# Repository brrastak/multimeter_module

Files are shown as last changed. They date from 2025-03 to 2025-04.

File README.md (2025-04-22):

# Module for Fluke 87V Multimeter

## Description

This module connects to the "COM" and "mA" inputs of the Fluke 87V multimeter. It allows you to:

- Disconnect the power source from the tested circuit.
- Short the multimeter's internal current shunt.
- Protect the multimeter using an external fuse.

Partially parametrized via spreadsheet in FreeCAD project.

## Printing

The enclosure was 3D printed using 0.2 mm layer height PETG filament.  
Threading for an M3 screw should be cut manually after printing.

## Images

### Photos

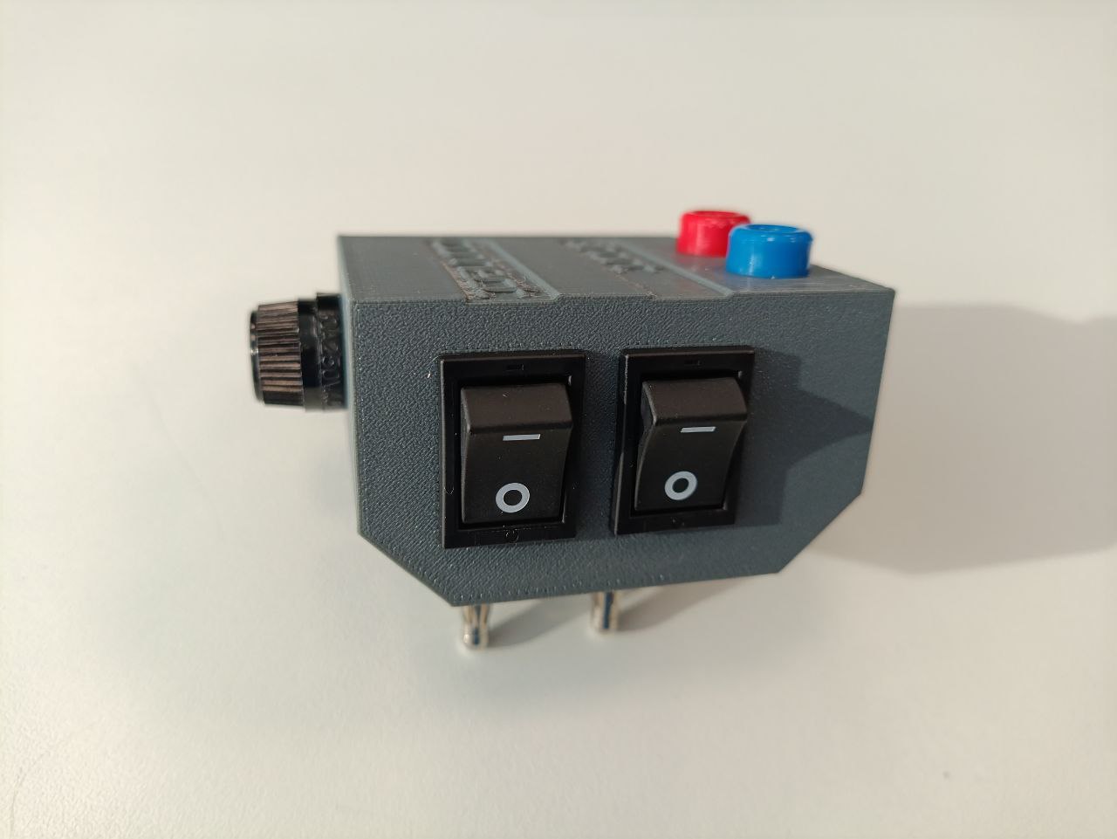
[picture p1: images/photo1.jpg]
Module

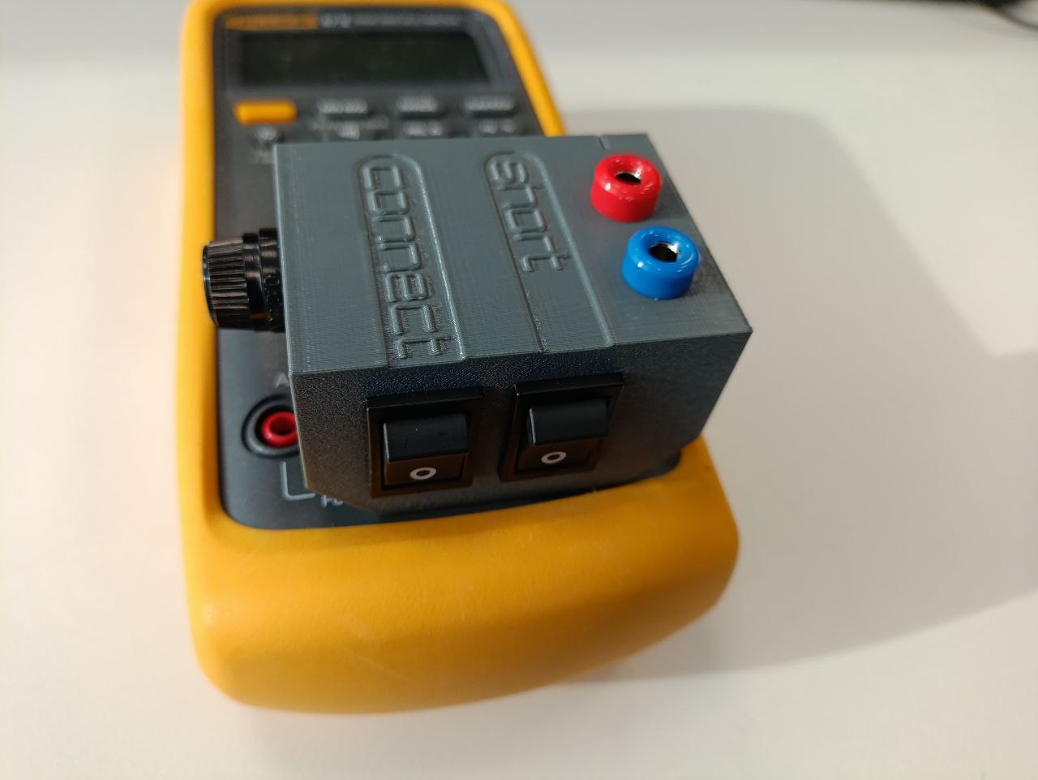
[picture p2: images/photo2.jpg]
Module + multimeter


### Drawings

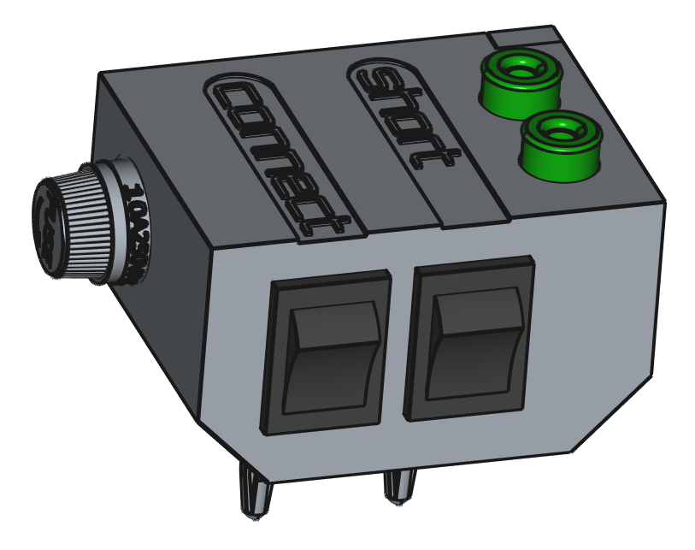
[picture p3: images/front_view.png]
Front view

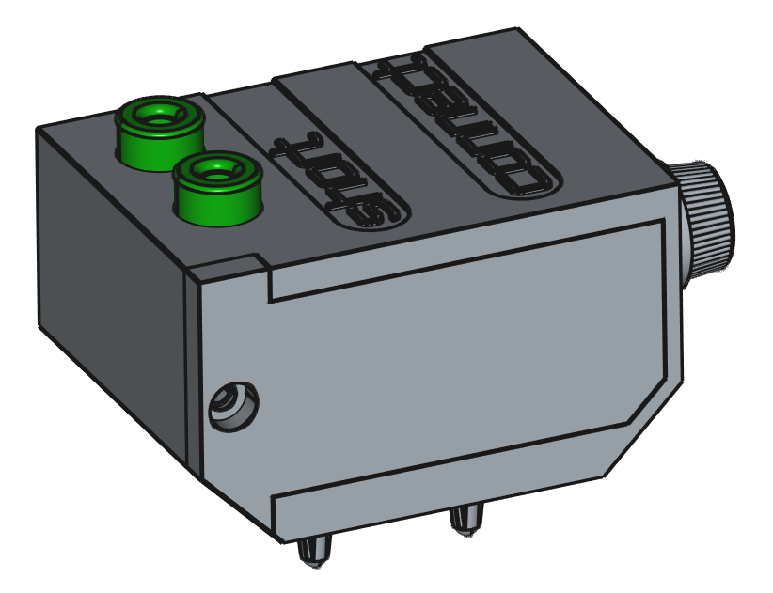
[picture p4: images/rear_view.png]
Rear view

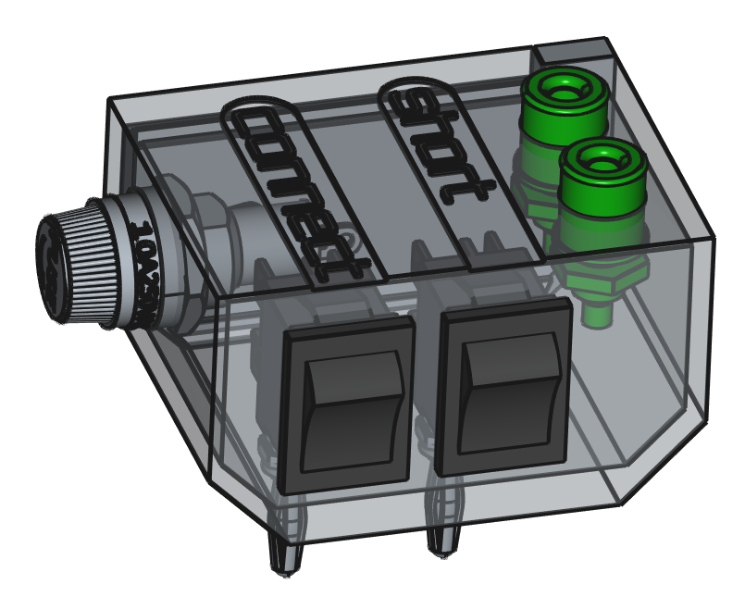
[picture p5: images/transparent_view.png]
Transparent view


### Schematic

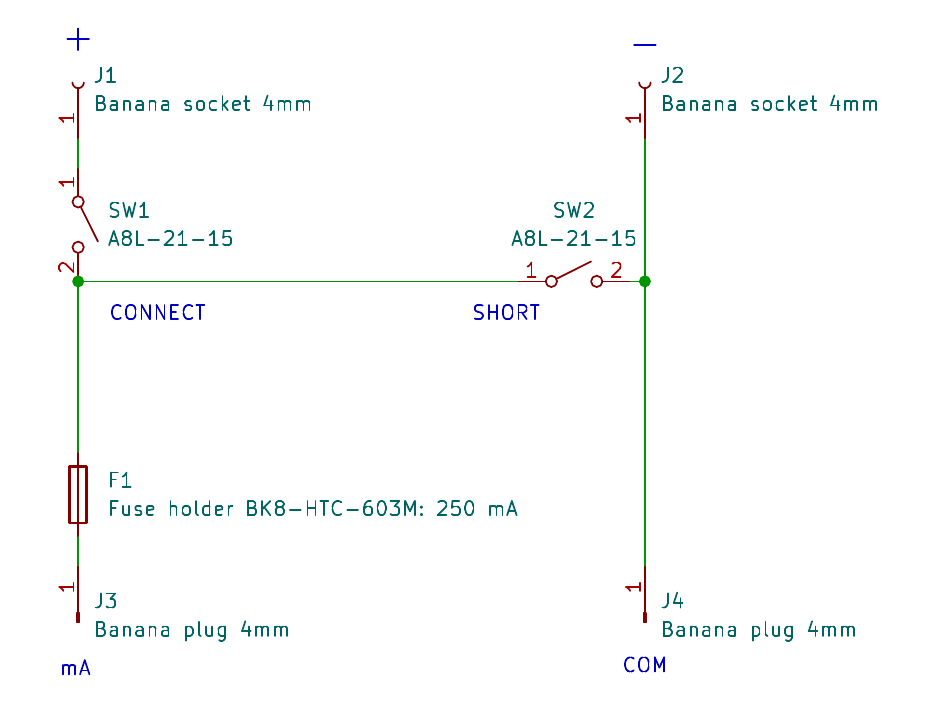
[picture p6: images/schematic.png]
Schematic


### Wiring

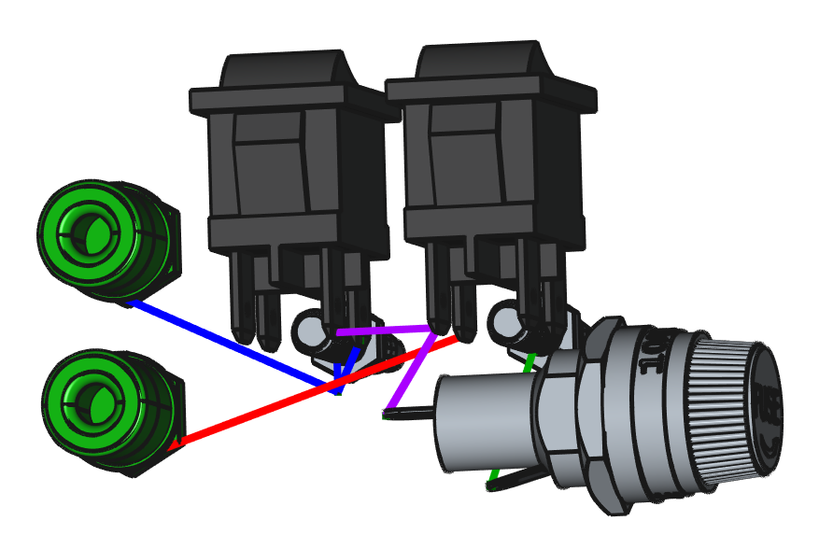
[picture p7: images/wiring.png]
Wiring


## Bill of Materials (BOM)

| Designator  | Description | Value | Qty | Farnell Code  | Note |
|---|---|---|-----|---|---|
| F1 | Fuse holder | BK8-HTC-603M  | 1 | 3769131 | |
| | Fast fuse | 250 mA | 1 | 3515934 | |
| J1, J2 | Banana socket 4mm/M6  | | 2 | 1698955 | |
| | Solder washer M6 | | 2 | 2832547 | |
| | Star lock washer M6 | | 2 | | |
| J3, J4 | Banana plug 4mm | FK 1210 NI | 2 | 3224621 | |
| | Solder washer M4 | | 2 | 2832545 | |
| | Nylon lock nut M4 | | 2 | | |
| SW1, SW2 | DPST switch | A8L-21-15 | 2 | 2213918 | SPST won't fit mechanically |
| | Blade connector 4.8 | | 4 | | |

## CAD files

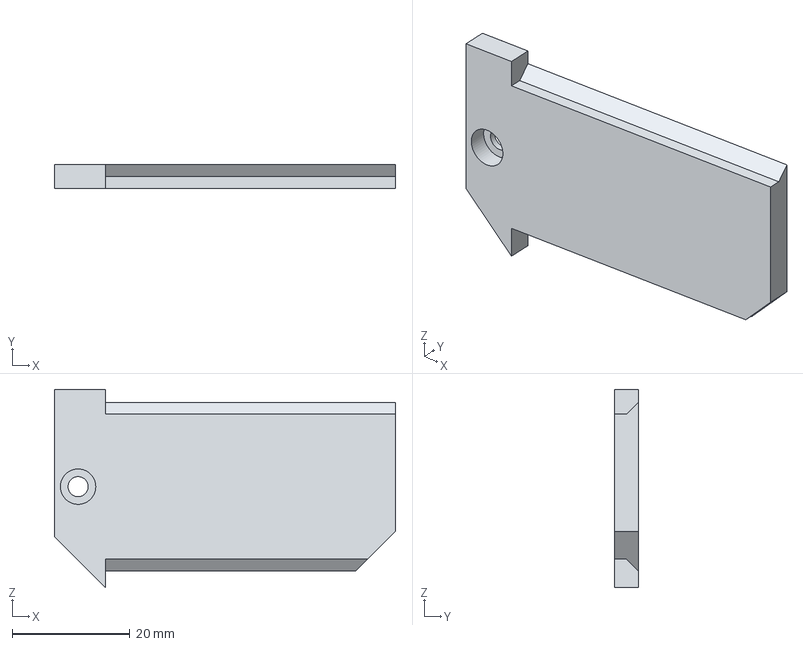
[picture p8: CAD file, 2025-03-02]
3D/lid.step
57.8 x 4.00 x 33.6 mm

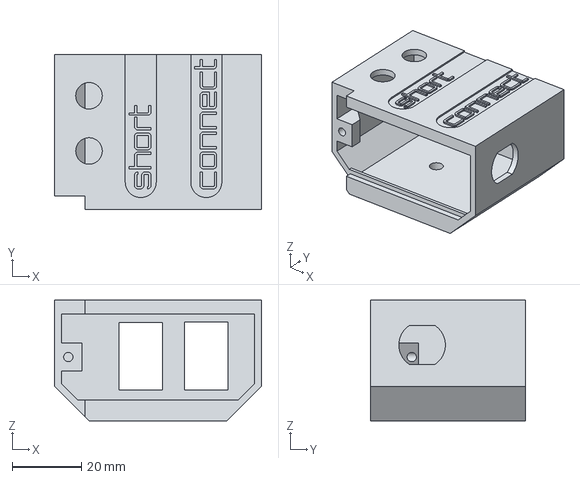
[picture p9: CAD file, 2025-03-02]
3D/box.step
60.0 x 45.0 x 35.0 mm

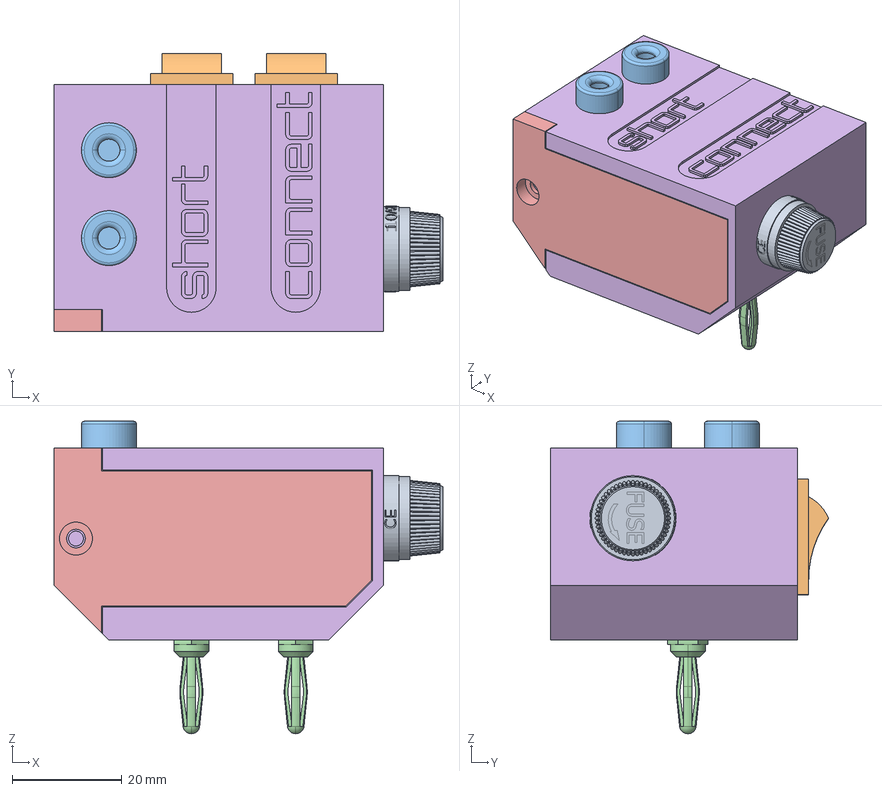
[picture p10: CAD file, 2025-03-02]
3D/multimeter_module.FCStd
70.8 x 50.6 x 56.9 mm
Fuse holder BK8-HTC-603M001
Switch a8l-11-15n11 x 2
Socket 4mm x 2
Plug 4mm x 2
Lid

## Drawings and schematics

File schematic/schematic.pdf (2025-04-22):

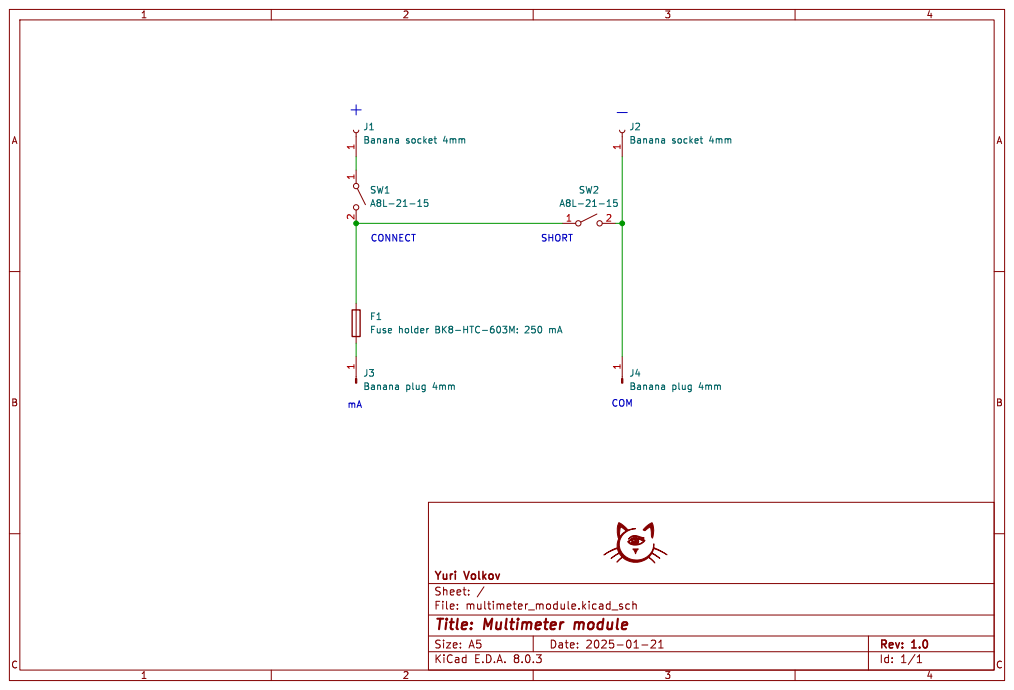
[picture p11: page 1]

File: multimeter_module.kicad_sch Sheet: / Yuri Volkov

Id: 1/1 Title: Multimeter module

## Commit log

2025-01-18 Add holes
    [multimeter_module.FCStd]
2025-01-19 Add components
    [multimeter_module.FCStd]
2025-01-19 Add asssembly joints
    [multimeter_module.FCStd]
2025-01-21 Remove 3rd plug
    [multimeter_module.kicad_sch]
2025-01-21 Remove 3rd plug and symmetry
    [multimeter_module.FCStd]
2025-01-22 Reshape holes
    [multimeter_module.FCStd]
2025-01-23 Add multimeter sockets picture
    [multimeter_module.FCStd]
2025-01-24 Fix plug joint
    [multimeter_module.FCStd]
2025-01-24 Attach multimeter picture
    [multimeter_module.FCStd]
2025-01-27 Fix plugs distance
    [multimeter_module.FCStd]
2025-01-27 Rearrange components & reshape box
    [multimeter_module.FCStd]
2025-01-28 Rotate fuseholder hole 90 deg
    [multimeter_module.FCStd]
2025-01-28 Add pull chamfers
    [multimeter_module.FCStd]
2025-01-30 Add lid shelves
    [multimeter_module.FCStd]
2025-01-30 Add lid entrance
    [multimeter_module.FCStd]
2025-01-30 Add screw holder
    [multimeter_module.FCStd]
2025-01-30 Add lid
    [multimeter_module.FCStd]
2025-02-09 Tune dimensions
    [multimeter_module.FCStd]
2025-02-13 Fix assembly joints
    [multimeter_module.FCStd]
2025-02-13 Change order of parts: increase pull chamfers
    [multimeter_module.FCStd]
2025-02-14 Rearrange components
    [multimeter_module.FCStd]
2025-02-14 Add text marks
    [multimeter_module.FCStd]
2025-02-21 Tune tolerances
    [multimeter_module.FCStd]
2025-02-21 Glue texts to box surface
    [multimeter_module.FCStd]
2025-02-25 Fix fuse holder hole size
    [multimeter_module.FCStd]
2025-02-25 Tune lid size
    [multimeter_module.FCStd]
2025-02-26 Make plug pockets deeper
    [multimeter_module.FCStd]
2025-02-26 Change lid for socket head screw
    [multimeter_module.FCStd]
2025-03-02 Add wiring
    [multimeter_module.FCStd]
2025-03-02 Add step export
    [box.step, lid.step]
2025-04-22 Fix switch name
    [multimeter_module.kicad_sch]
2025-04-22 Add BOM
